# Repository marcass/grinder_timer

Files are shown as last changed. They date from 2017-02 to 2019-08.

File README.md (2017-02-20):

# grinder_timer
timer switch for coffee grinder
* Adjustable time for grind or grind on demand
* LCD display
* small circuit board for mounting inside grinder chasis

## Timer adjustment
* Option for rotary encoder
* Option for potentiometer

### Rotary encoder

* Useful for user defined adjustment steps (eg 50ms or 100ms)
* Setup a little trickier
* https://forum.arduino.cc/index.php?topic=242356.0 FOR ROATRY ENCODER
* https://github.com/0xPIT/encoder/tree/arduino
* https://www.circuitsathome.com/mcu/reading-rotary-encoder-on-arduino/

### Potentiometer

* Easy setup
* Timer value will change with heat of potentiometer
* Increments depend on temp and potentiometer used
* Using 10k pot

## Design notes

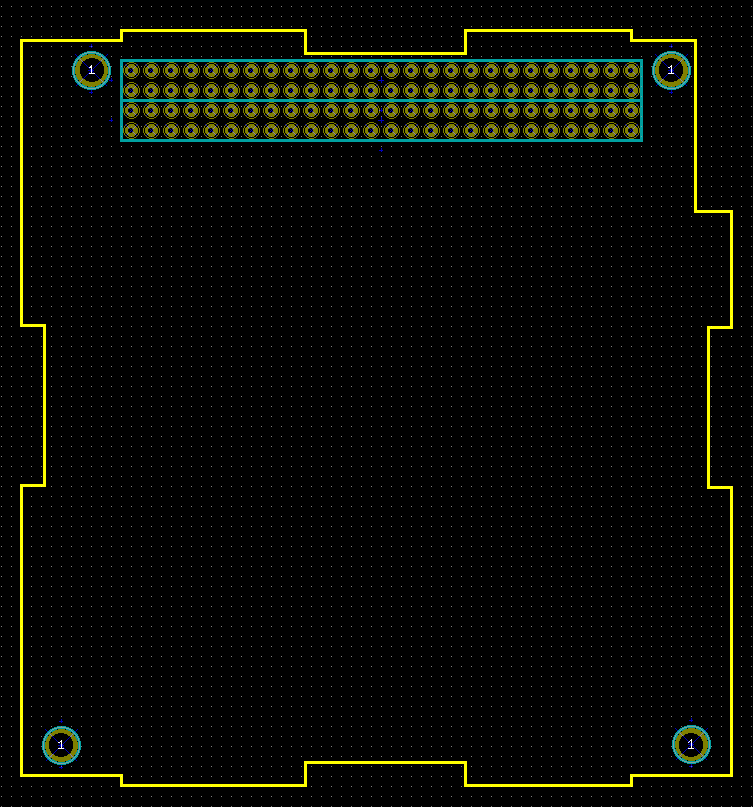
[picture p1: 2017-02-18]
kicad/kicad_lib/KiCad-Libraries-master/Templates/CubeSatKit_StackBoard/meta/Board.png

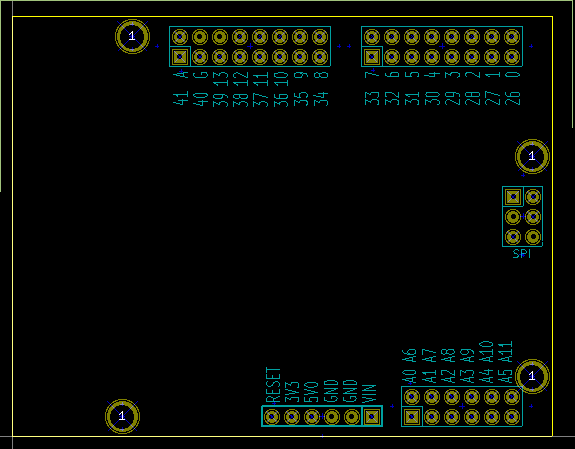
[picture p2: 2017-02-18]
kicad/kicad_lib/KiCad-Libraries-master/Templates/Chipkit_Shield_uC/meta/board.png

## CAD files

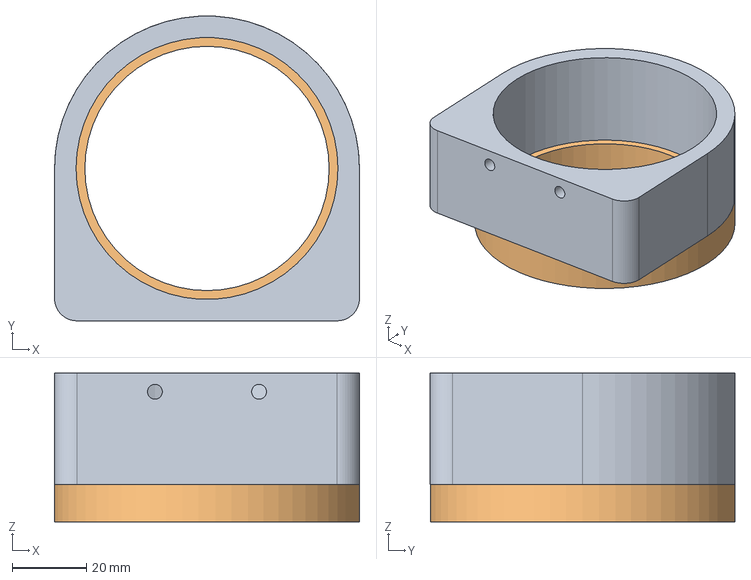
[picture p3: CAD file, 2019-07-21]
cad/grindercad.FCStd
82.1 x 82.0 x 40.0 mm

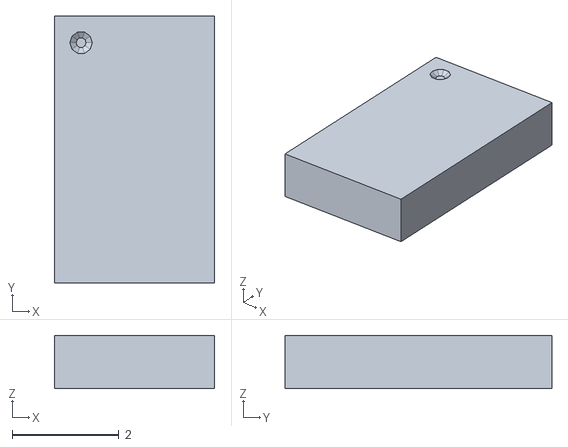
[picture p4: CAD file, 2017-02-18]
kicad/kicad_lib/KiCad-Libraries-master/3D/SourceFiles/ADXL345/ADXL345-Wings.stl
3.00 x 5.00 x 1.00

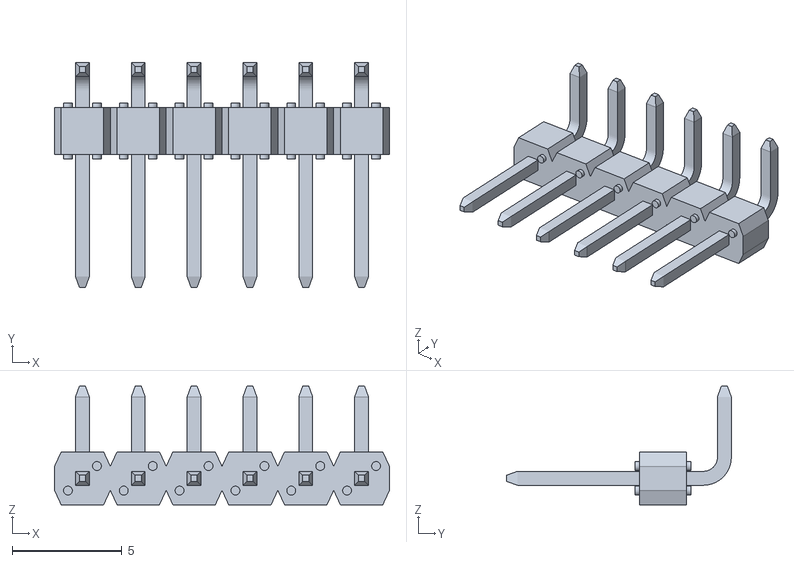
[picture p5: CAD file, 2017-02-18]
kicad/kicad_lib/KiCad-Libraries-master/3D/SourceFiles/Connectors/CONN_1x6/CONN_1x6_Male.stl
15.2 x 10.2 x 5.40

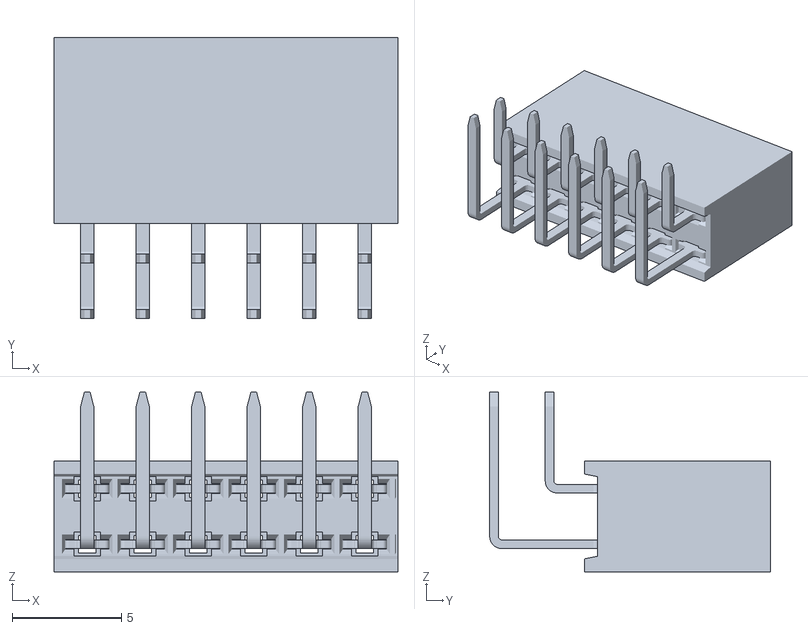
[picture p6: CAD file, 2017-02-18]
kicad/kicad_lib/KiCad-Libraries-master/3D/SourceFiles/Connectors/CONN_2x6/CONN_2x6_Female.stl
15.7 x 12.8 x 8.23

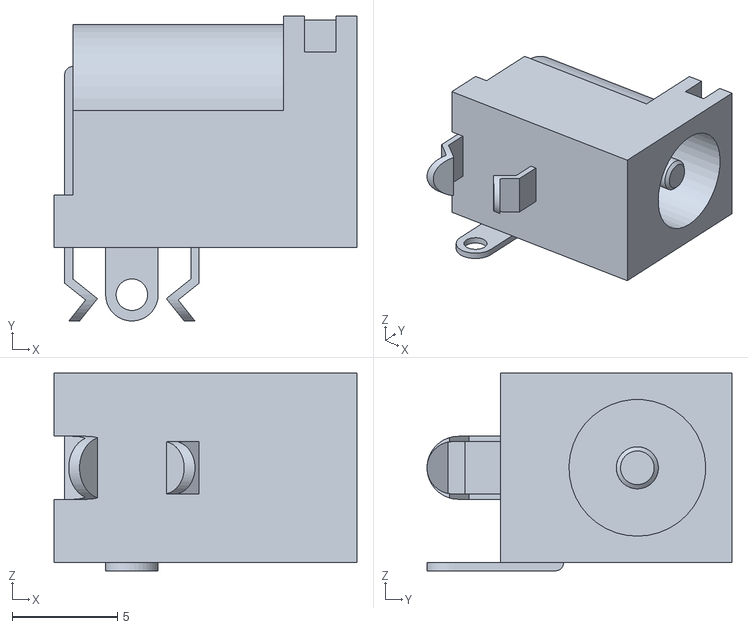
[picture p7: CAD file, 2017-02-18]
kicad/kicad_lib/KiCad-Libraries-master/3D/SourceFiles/Connectors/DC_2.1mm_CUI-PJ-202A/DC_2.1mm_CUI-PJ-202A.stl
14.4 x 14.5 x 9.40

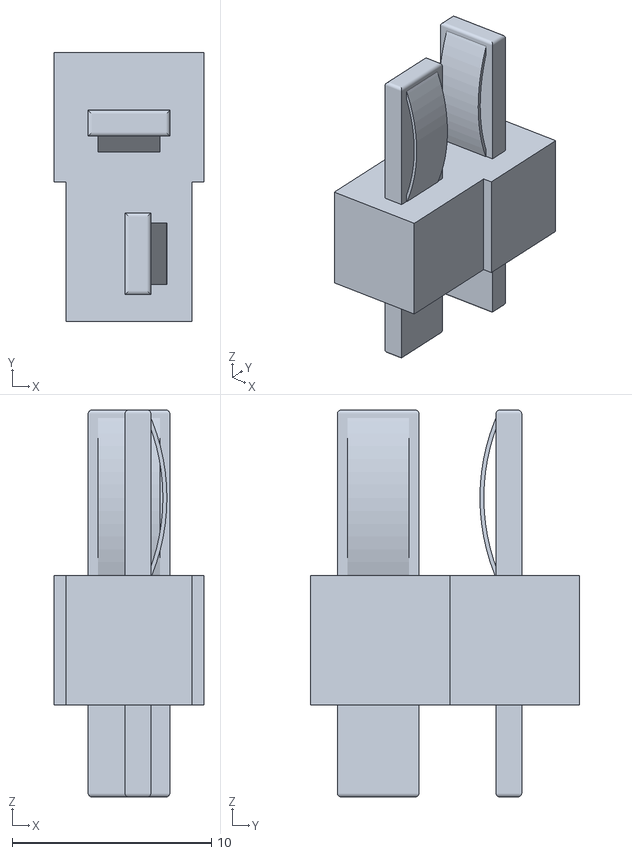
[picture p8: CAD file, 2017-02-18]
kicad/kicad_lib/KiCad-Libraries-master/3D/SourceFiles/Connectors/Deans/Deans-Wings.stl
7.50 x 13.5 x 19.4

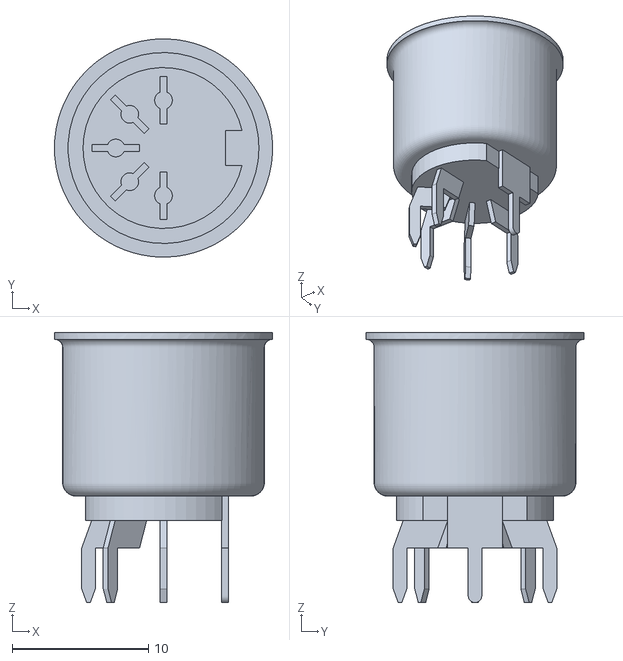
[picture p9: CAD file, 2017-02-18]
kicad/kicad_lib/KiCad-Libraries-master/3D/SourceFiles/Connectors/DIN_CUI_SD-50BV/SD-50BV.stl
16.0 x 16.0 x 19.8

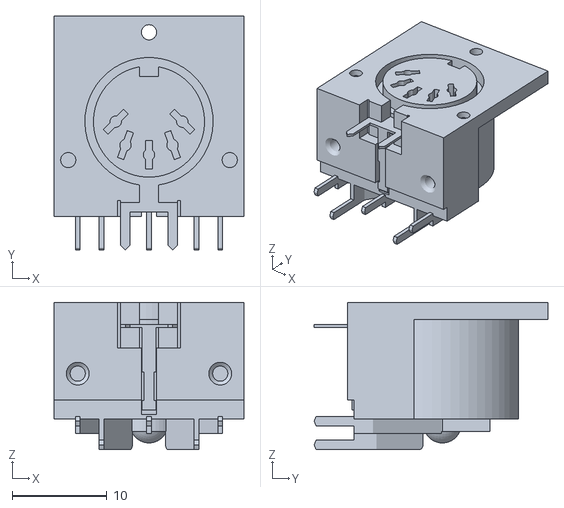
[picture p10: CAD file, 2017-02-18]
kicad/kicad_lib/KiCad-Libraries-master/3D/SourceFiles/Connectors/DIN_CUI_SDS-50J/SDS-50J.stl
20.0 x 24.6 x 15.5

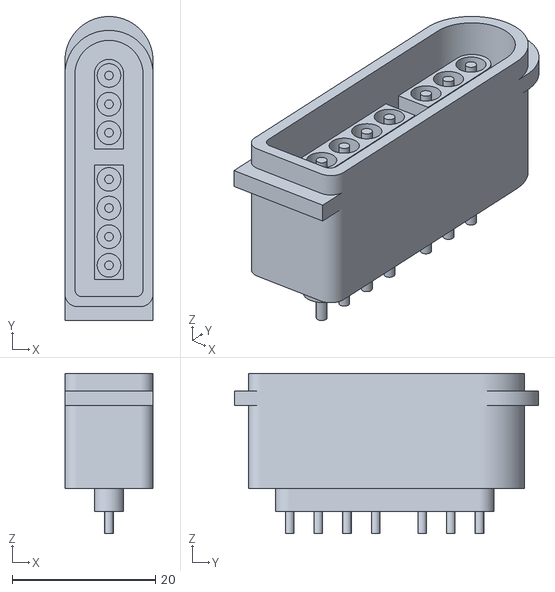
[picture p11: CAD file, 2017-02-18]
kicad/kicad_lib/KiCad-Libraries-master/3D/SourceFiles/Connectors/Gaming_SNES/Gaming_SNES-wings.stl
12.3 x 42.4 x 22.3

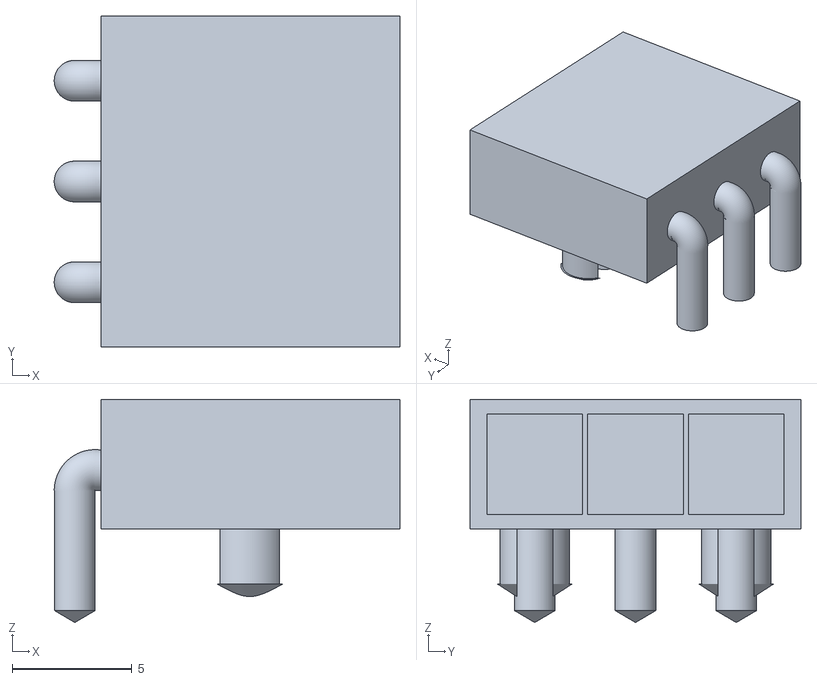
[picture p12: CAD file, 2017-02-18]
kicad/kicad_lib/KiCad-Libraries-master/3D/SourceFiles/Connectors/MOLEX_MINI-FIT-JR_3_PTH_RT_PEG/MOLEX_MINI-FIT-JR_3_PTH_RT_PEG-scad.stl
14.4 x 13.8 x 9.30

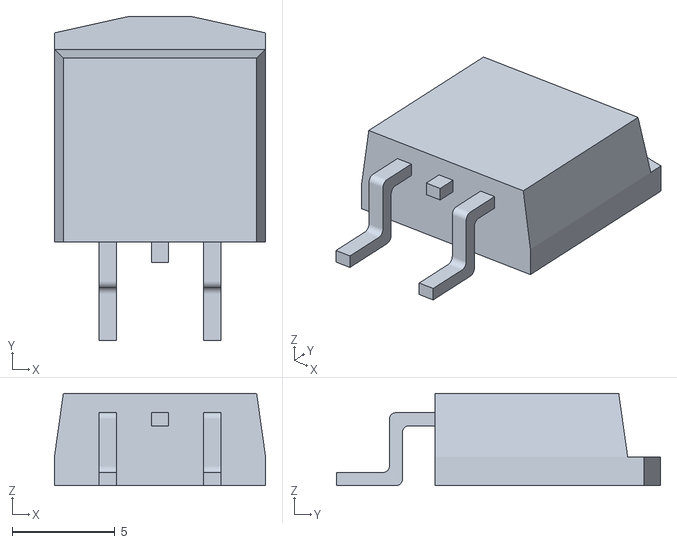
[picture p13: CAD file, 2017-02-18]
kicad/kicad_lib/KiCad-Libraries-master/3D/SourceFiles/D2PACK/D2PACK-SCAD.stl
10.3 x 15.8 x 4.50

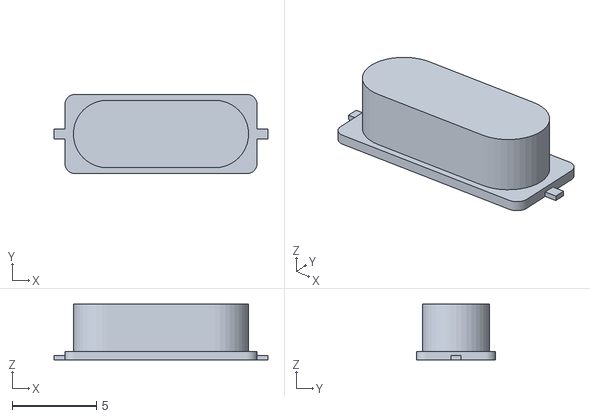
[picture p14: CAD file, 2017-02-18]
kicad/kicad_lib/KiCad-Libraries-master/3D/SourceFiles/HC-49-SMT/HC-49-SMT-wings.stl
12.7 x 4.70 x 3.30

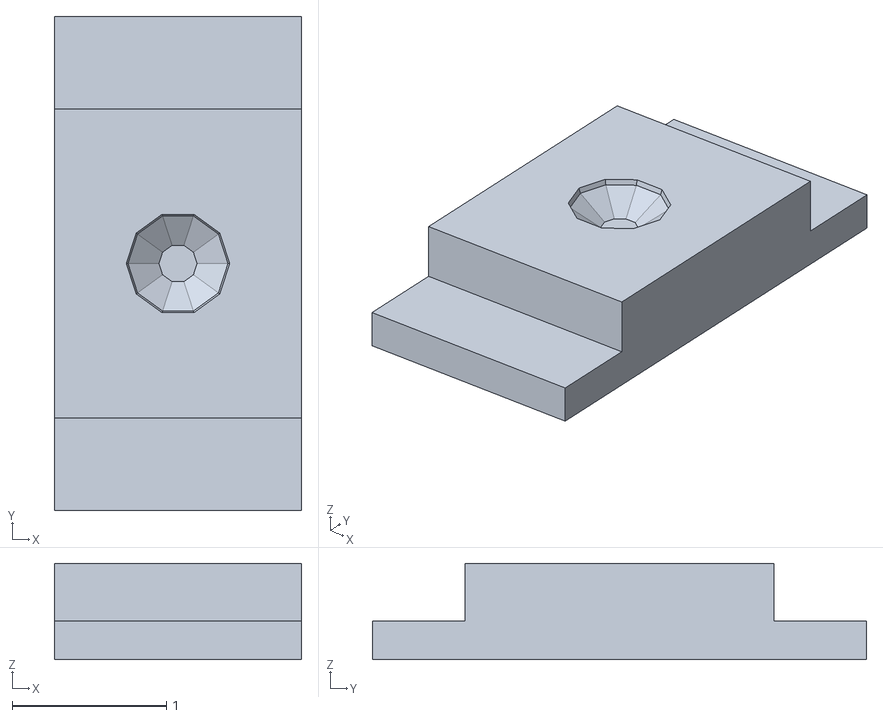
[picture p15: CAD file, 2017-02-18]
kicad/kicad_lib/KiCad-Libraries-master/3D/SourceFiles/LEDs/LED-1206-SCAD.stl
1.60 x 3.20 x 0.625

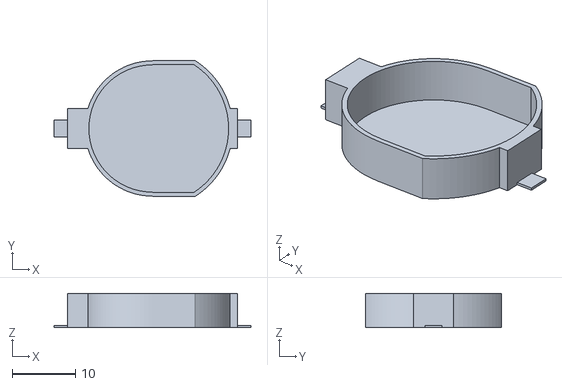
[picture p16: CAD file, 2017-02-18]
kicad/kicad_lib/KiCad-Libraries-master/3D/SourceFiles/MPD_CR2032/MPD_CR2032-Wings.stl
31.1 x 21.4 x 5.38

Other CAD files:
kicad/kicad_lib/KiCad-Libraries-master/3D/SourceFiles/MPU9150/MPU9150-SCAD.stl
kicad/kicad_lib/KiCad-Libraries-master/3D/SourceFiles/SD_Objects/SD-Amp-microSlot-Wings.stl
kicad/kicad_lib/KiCad-Libraries-master/3D/SourceFiles/Sensors/SHARP_GP1A57HRJ00F-wings.stl
kicad/kicad_lib/KiCad-Libraries-master/3D/SourceFiles/SMD_Passives/SMD-1206-scad.stl
kicad/kicad_lib/KiCad-Libraries-master/3D/SourceFiles/Sensors/SHARP_GP1A57HRJ00F.scad
kicad/kicad_lib/KiCad-Libraries-master/3D/SourceFiles/ADXL345/ADXL345.scad
kicad/kicad_lib/KiCad-Libraries-master/3D/SourceFiles/D2PACK/D2PACK.scad
kicad/kicad_lib/KiCad-Libraries-master/3D/SourceFiles/HC-49-SMT/HC-49-SMT.scad
kicad/kicad_lib/KiCad-Libraries-master/3D/SourceFiles/ADXL345/ADXL345-SCAD.stl
kicad/kicad_lib/KiCad-Libraries-master/3D/SourceFiles/Connectors/CONN_1x6/CONN_1x6_Female.stl
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

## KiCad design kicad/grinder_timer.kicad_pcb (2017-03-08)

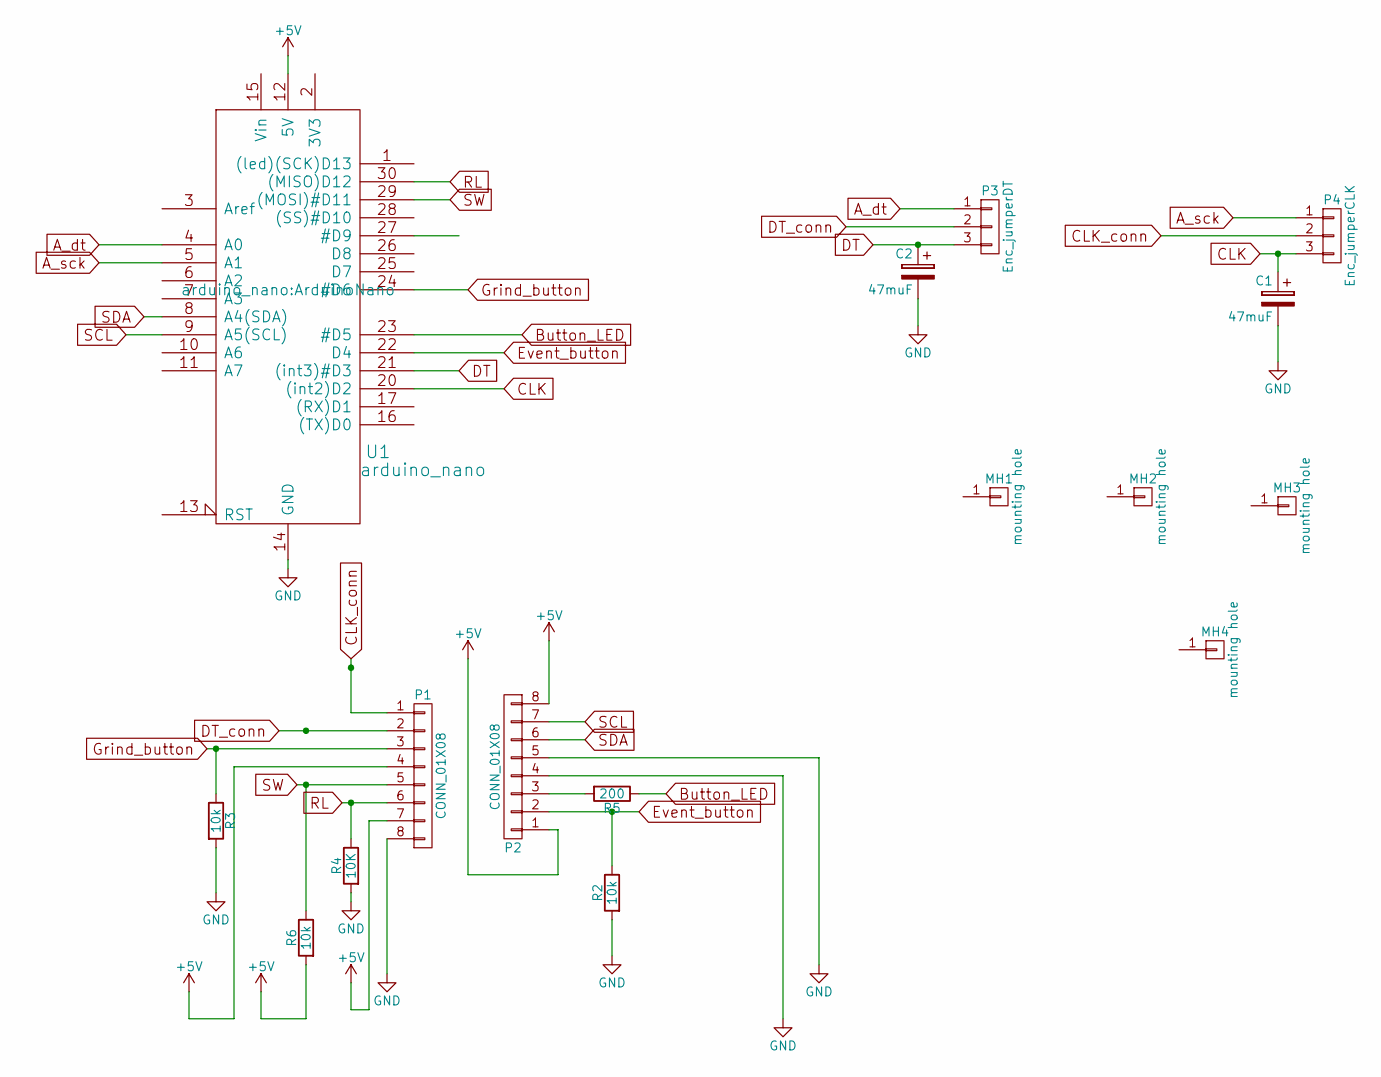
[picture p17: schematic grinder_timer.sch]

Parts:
C1, C2: 47muF; CP_Radial_D10.0mm_P3.50mm
MH1, MH2, MH3, MH4: mounting hole; MountingHole_3.2mm_M3_DIN965_Pad
P1, P2: CONN_01X08; PhoenixContact_MCV-G_08x3.50mm_Vertical
P3: Enc_jumperDT; Pin_Header_Straight_1x03
P4: Enc_jumperCLK; Pin_Header_Straight_1x03
R2, R3, R6: 10k; R_Axial_DIN0207_L6.3mm_D2.5mm_P10.16mm_Horizontal
R4: 10K; R_Axial_DIN0207_L6.3mm_D2.5mm_P10.16mm_Horizontal
R5: 200; R_Axial_DIN0207_L6.3mm_D2.5mm_P10.16mm_Horizontal
U1: arduino_nano; ArduinoNano

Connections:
+5V: P1.4, P1.7, P2.1, P2.8, R6.2, U1.12 (5V)
A_dt: P3.1, U1.4 (A0)
A_sck: P4.1, U1.5 (A1)
Button_LED: R5.1, U1.23 (#D5)
CLK: C1.1, P4.3, U1.20 ((int2)D2)
CLK_conn: P1.1, P4.2
DT: C2.1, P3.3, U1.21 ((int3)#D3)
DT_conn: P1.2, P3.2
Event_button: P2.2, R2.1, U1.22 (D4)
GND: C1.2, C2.2, P1.8, P2.4, P2.5, R2.2, R3.2, R4.2, U1.14 (GND), U1.19 (GND)
Grind_button: P1.3, R3.1, U1.24 (#D6)
unnamed: P2.3, R5.2
RL: P1.6, R4.1, U1.30 ((MISO)D12)
SCL: P2.7, U1.9 (A5(SCL))
SDA: P2.6, U1.8 (A4(SDA))
SW: P1.5, R6.1, U1.29 ((MOSI)#D11)

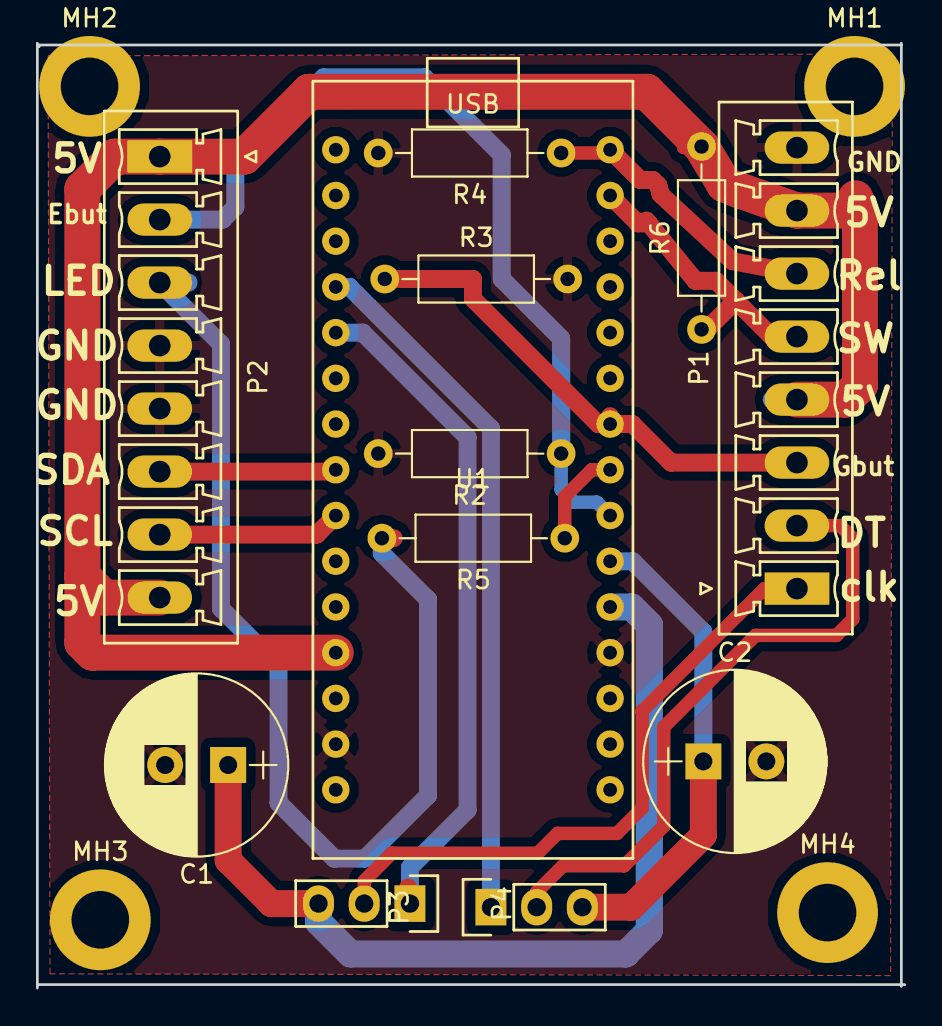
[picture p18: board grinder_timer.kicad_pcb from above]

Board: 2 copper layers, 48.2 x 52.5 mm, 16 parts (0 on the bottom side), 16 nets.

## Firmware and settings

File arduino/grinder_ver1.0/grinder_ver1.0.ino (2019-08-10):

//Runs a mazzer superjolly grinder with timer

#define debug

#include <Wire.h>
#include <Adafruit_GFX.h>
#include <Adafruit_SSD1306.h>
#include <Fonts/FreeSans12pt7b.h>

//preset storage (from reboot for rotary encoder value)
#include <EEPROM.h>
#include "./EEPROMAnything.h"
//#include "/home/mw/git/grinder_timer/rot_encoder_live/EEPROMAnything.h"

struct config_t
{
   int preset;
} configuration;

//******************** setup encoder*************
#define ENC_PORT PINC
const int CLK = A0;
const int DT = A1; 


//*********************** Setup dislplay ************
#define SCREEN_WIDTH 128 // OLED display width, in pixels
#define SCREEN_HEIGHT 64 // OLED display height, in pixels

// Declaration for an SSD1306 display connected to I2C (SDA, SCL pins) adn no reset pin
Adafruit_SSD1306 display(SCREEN_WIDTH, SCREEN_HEIGHT, &Wire, -1);


//************************ presets ***************
const int MIN_GRIND_TIME = 5000;
const int MAX_GRIND_TIME = 15000;
const int STATE_IDLE = 0;
const int STATE_GRINDING = 1;
const int STATE_DONE = 2;
const int MODE_TIMER = 0;
const int MODE_DEMAND = 1;
const int COOL_DOWN = 3000; //number of seconds to cool down after grinding
const long EEPROM_ADJ_THRESH = 600000; //10min
const int DEBOUNCE_DELAY = 50;
//pins
const int GRIND_BUTTON = 6;
const int EVENT_BUTTON = 5; 
const int STATUS_LED_PIN = 9; // pin9 is a PWM pin and allows for analogWrite.
const int RELAY_PIN_L = 12;

//********************* variables ******************
unsigned long grind_time_preset;
unsigned long new_preset;
unsigned long grind_start = 0;
unsigned long grind_time = 0;
unsigned long adjust_time_start = 0;
char buf[16];
int state = STATE_IDLE;
int mode = MODE_TIMER;
bool newPreset = false;
bool timer_starts;
unsigned long mode_debounce_time = 0;
unsigned long grind_debounce_time = 0;
int status_led_brightness = 0;
int fade_rate = 10;
bool change_disp = true;


void setup() {
  //Initialise display
  if(!display.begin(SSD1306_SWITCHCAPVCC, 0x3C)) { // Address 0x3D for 128x64
    Serial.println(F("SSD1306 allocation failed"));
    for(;;);
  }
  delay(2000);
  display.clearDisplay();
  // initialize the button pin as an input
  pinMode(GRIND_BUTTON, INPUT);
  digitalWrite(GRIND_BUTTON, LOW);
  // initialize the button LED as an output
  pinMode(STATUS_LED_PIN, OUTPUT);
  // initialize the RELAY as an output
  pinMode(RELAY_PIN_L, OUTPUT);
  digitalWrite(RELAY_PIN_L, LOW);  
  //initialize event button
  pinMode(EVENT_BUTTON, INPUT);
  digitalWrite(EVENT_BUTTON, LOW); 
  /* Setup encoder pins as inputs */
  pinMode(CLK, INPUT);
  digitalWrite(CLK, HIGH);
  pinMode(DT, INPUT);
  digitalWrite(DT, HIGH);
  Serial.begin (115200);
  Serial.println("Start");
  //read preset storage
  EEPROM_readAnything(0, configuration);
  if (configuration.preset == -1) {
    grind_time_preset = 6000;
  }else {
    grind_time_preset = configuration.preset;
  }
  EEPROM_writeAnything(0, configuration);
//  Serial.print("Grind time preset = ");
//  Serial.println(grind_time_preset);
  // initialize display
  display.clearDisplay();
  display.setFont(&FreeSans12pt7b);
  display.setTextSize(1);
  display.setTextColor(WHITE);
  display.setCursor(0, 20);
  // Display static text
  display.println("Lets Grind");
  display.display(); 
  delay(2000);
  update_display();
}


void update_display(){
  switch (state) { 
    case STATE_GRINDING:
      if (mode==MODE_TIMER) {
        float bar_frac;
        bar_frac = (float)grind_time/(float)grind_time_preset * 100;
        #ifdef debug
          Serial.print("Grind time is: ");
          Serial.print(grind_time);
          Serial.print(", Preset is: ");
          Serial.print(grind_time_preset);
          Serial.print(", bar_frac is: ");
          Serial.println(bar_frac);
        #endif
        display.clearDisplay();
        display.setFont();
        display.setTextSize(1);
        display.setTextColor(WHITE);
        display.setCursor(0, 0);
        display.println("Crushing beans...");
        drawPercentbar( 0, 40, 128, 20, (int)bar_frac);
        display.display();
      }
      if (mode == MODE_DEMAND) {
        display.clearDisplay();
        display.setFont(&FreeSans12pt7b);
        display.setTextSize(1);
        display.setTextColor(WHITE);
        display.setCursor(0, 20);
        display.println("GRAAHHH...");
        display.display();
      }
      break;
    case STATE_IDLE:
      if(change_disp) {
        display.clearDisplay();
//        for bigger sans serif text
//        display.setFont(&FreeSans12pt7b);
//        display.setTextSize(1);
//        display.setTextColor(WHITE);
//        display.setCursor(0, 20);
//        for mono small text
        display.setFont();
        display.setTextSize(1);
        display.setTextColor(WHITE);
        display.setCursor(0, 0);
        // Display static text
        if (mode == MODE_DEMAND){
          display.println("Mode: Demand");
          display.setFont(&FreeSans12pt7b);
          display.setCursor(0, 40);
          display.println("I await");
        }else{
          display.println("Mode: Timer");
          display.setFont(&FreeSans12pt7b);
          display.setCursor(0, 40);
          display.print(grind_time_preset);
          display.println(" ms");
//          display.setCursor(0, 60);
//          display.println("grind");
        }        
        display.display(); 
        change_disp = false;
      }
      break;
    case STATE_DONE:
      display.clearDisplay();
      display.setFont(&FreeSans12pt7b);
      display.setTextSize(1);
      display.setTextColor(WHITE);
      display.setCursor(0, 20);
      // Display static text
      display.println("Done");
      display.setCursor(0, 40);
      display.setFont();
      display.println("Calming down");
      display.setCursor(0,50);
      display.println("Be patient");
      display.display();
      change_disp = true;
      break;
  }
}

void mode_change() {
  if (mode == MODE_TIMER) {
    mode = MODE_DEMAND;
    delay(500);
  }
  else if (mode == MODE_DEMAND) {
    mode = MODE_TIMER;
    delay(500);
  }
  change_disp = true;
}


void proc_idle() {
 static uint8_t counter = 0;   //this variable will be changed by encoder input
 int8_t tmpdata;
 int x;
 /**/
  tmpdata = read_encoder();
  if( tmpdata ) {
//    Serial.print("Counter value: ");
//    Serial.print(counter, DEC);
//    Serial.print("tmpdata: ");
//    Serial.print(tmpdata);   
//    Serial.print("  Grind time = ");
//    Serial.println(grind_time_preset);
    counter += tmpdata;
    x = counter % 4;
    if (x == 0) {
      new_preset = (grind_time_preset + (tmpdata * 50));
      if (new_preset > MAX_GRIND_TIME) {
        grind_time_preset = MAX_GRIND_TIME;
      }else if (new_preset < MIN_GRIND_TIME) {
        grind_time_preset = MIN_GRIND_TIME;
      }else {
        grind_time_preset = new_preset;
      }
      change_disp = true;
      update_display();
      newPreset = true;
    }
//  Serial.print("Counter value: ");
//  Serial.print(counter, DEC);
//  Serial.print("  Grind time = ");
//  Serial.println(grind_time_preset);
  }
  if (digitalRead(EVENT_BUTTON) == HIGH) { 
  //do debounce stuff
  if (mode_debounce_time == 0){
    mode_debounce_time = millis();
    }
    if (millis() - mode_debounce_time > DEBOUNCE_DELAY) {
      //over debounce threshold so change mode
      mode_debounce_time = 0;
      mode_change();
      update_display();
    }
  }
  if (mode == MODE_TIMER) {
    if (digitalRead(GRIND_BUTTON) == HIGH) { 
      //do debounce stuff
      if (grind_debounce_time == 0){
        grind_debounce_time = millis();
      }
      if (millis() - grind_debounce_time > DEBOUNCE_DELAY) {
        //over debounce threshold so change state
        grind_start = 0;
        grind_time = 0;
        timer_starts = true;
        state = STATE_GRINDING;
        update_display();
        grind_debounce_time = 0;
      }
    }
  }
  //if not in timer mode need to grind on button push
  if (mode == MODE_DEMAND) {
    if (digitalRead(GRIND_BUTTON) == HIGH) { 
      //do debounce stuff
      if (grind_debounce_time == 0){
        grind_debounce_time = millis();
      }
      if (millis() - grind_debounce_time > DEBOUNCE_DELAY) {
        //over debounce threshold so change state
        state = STATE_GRINDING;
        update_display();
        grind_debounce_time = 0;
      }
    }
  }
}

void proc_grinding(){
  update_display();
  if (mode == MODE_TIMER) {
    //set flag for timer start
    if (timer_starts) {
      grind_start = millis();
      timer_starts = false;
    }
    grind_time = millis() - grind_start;   //grinding ends if grind time reached or event button is pressed to cancel
    if (grind_time > grind_time_preset){
      #ifdef debug
        Serial.println("dropped out of grinding due to time reset trigger");
      #endif
      state = STATE_DONE;
      update_display();
    }
    //handle a cancellation with push of event button
    if (digitalRead(EVENT_BUTTON) == HIGH) { 
    //do debounce stuff
      if (mode_debounce_time == 0){
        mode_debounce_time = millis();
      }
      if (millis() - mode_debounce_time > DEBOUNCE_DELAY) {
        //over debounce threshold so stop grinding
        mode_debounce_time = 0;
        #ifdef debug
          Serial.println("Killed by event button");
        #endif
        state = STATE_DONE;
        update_display();
      }
    }
  }
  if (mode == MODE_DEMAND) {   //grind on demand so while button is pushed we will grind
    if (digitalRead(GRIND_BUTTON) == LOW){
      state = STATE_DONE;
      update_display();
    }
  }
}

void proc_done(){
  update_display();
  if (digitalRead(GRIND_BUTTON) == LOW) {
     manage_outputs();
     if (mode == MODE_TIMER) {
       delay(COOL_DOWN);
       state = STATE_IDLE;
     }
     if (mode == MODE_DEMAND) {
       state = STATE_IDLE;
     }
     update_display();
  }
}

void manage_outputs(){
  if (state == STATE_GRINDING){
    digitalWrite(RELAY_PIN_L, HIGH);
//    digitalWrite(RELAY_PIN_N, HIGH);
    analogWrite(STATUS_LED_PIN, status_led_brightness);
    status_led_brightness += fade_rate;    
    if (status_led_brightness <= 0 || status_led_brightness >= 255) {
      fade_rate = -fade_rate;
    }
    //delay(1); // delay to see fade
  }else{
    digitalWrite(RELAY_PIN_L, LOW);
//    digitalWrite(RELAY_PIN_N, LOW);
    digitalWrite(STATUS_LED_PIN, HIGH);
  }
}


void loop() {
  manage_outputs();
  switch (state) {
    case STATE_IDLE:
      proc_idle();
      break;
    case STATE_GRINDING:
      proc_grinding();
      break;
    case STATE_DONE:
      proc_done();
      break;
  }
  if (newPreset) { //start timer for EEPROM write
    Serial.println("new preset so waiting");
    if (adjust_time_start == 0 ) {
      adjust_time_start = millis();
    }
    if(millis() - adjust_time_start > EEPROM_ADJ_THRESH) {
      configuration.preset = grind_time_preset;
      EEPROM_writeAnything(0, configuration);
      newPreset = false;
      adjust_time_start = 0;
      Serial.print("wrote data  ");
      Serial.println(configuration.preset);
    }
  }
}

void drawPercentbar(int x,int y, int width,int height, int progress) {
//  display.clearDisplay();
  display.setFont();
  display.setTextSize(1);
  float bar = ((float)(width-4) / 100) * progress; 
  display.drawRect(x, y, width, height, WHITE);
  display.fillRect(x+2, y+2, bar , height-4, WHITE);
  // Display progress text
  if( height >= 15){
    display.setCursor((width/2) -3, y+5 );
    display.setTextSize(1);
    display.setTextColor(WHITE);
  if( progress >=50)
    display.setTextColor(BLACK, WHITE); // 'inverted' text
    display.print(progress);
    display.print("%");
  }
//  display.display();
}
 
/* returns change in encoder state (-1,0,1) */
int8_t read_encoder()
{
  static int8_t enc_states[] = {0,-1,1,0,1,0,0,-1,-1,0,0,1,0,1,-1,0};
  static uint8_t old_AB = 0;
  /**/
  old_AB <<= 2;                   //remember previous state
  old_AB |= ( ENC_PORT & 0x03 );  //add current state
  return ( enc_states[( old_AB & 0x0f )]);
}

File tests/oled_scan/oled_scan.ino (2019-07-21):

/*********
  Rui Santos
  Complete project details at https://randomnerdtutorials.com
*********/

#include <Wire.h>

void setup() {
  Wire.begin();
  Serial.begin(115200);
  Serial.println("\nI2C Scanner");
}

void loop() {
  byte error, address;
  int nDevices;
  Serial.println("Scanning...");
  nDevices = 0;
  for(address = 1; address < 127; address++ ) {
    Wire.beginTransmission(address);
    error = Wire.endTransmission();
    if (error == 0) {
      Serial.print("I2C device found at address 0x");
      if (address<16) {
        Serial.print("0");
      }
      Serial.println(address,HEX);
      nDevices++;
    }
    else if (error==4) {
      Serial.print("Unknow error at address 0x");
      if (address<16) {
        Serial.print("0");
      }
      Serial.println(address,HEX);
    }
  }
  if (nDevices == 0) {
    Serial.println("No I2C devices found\n");
  }
  else {
    Serial.println("done\n");
  }
  delay(5000);
}

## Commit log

2017-01-23 Placed mode button. Need to finish later
2017-01-24 added relay for neutral, updated to active low relays and tidied logic
2017-01-26 button logic continues....
2017-01-26 fixed logic issues on switches
2017-01-26 solved some issues, cannot get state to gho form demand to timer and vice versa as varialbe event_press not being updated
2017-01-26 Working now. To do: relays on startup and LCD updates
2017-01-27 Fixed logic issues. Check relays then build!
2017-01-27 fixed relays starting on startup (was connected to pin 13)
2017-01-29 PWM for LED button
2017-01-31 changed grind timer form interrupt to button press in loop
2017-02-01 Pulled mode change out of interrupt and into button read
2017-02-01 Cleaned up and attempted fix for failed event interrupt
2017-02-02 new fix for poor timer after cancel performance
2017-02-02 new new fix for poor timer after cancel performance
2017-02-02 bool test for grinder timer start
2017-02-02 bool test for grinder timer start adn more variable manip
2017-02-02 fix for swithing modes timer failure initially
2017-02-02 fix for swithing modes timer failure initially. again
2017-02-02 fix for swithing modes timer failure initially. again..
2017-02-03 fix for swithing modes timer failure initially. again...
2017-02-03 interrupts chnaged again
2017-02-03 interrupt flags set
2017-02-03 remove all double refs to interrupts
2017-02-05 removed final interrupt
2017-02-18 Remove neutral switching
2017-02-18 added kicad
    [ADXL345-SCAD.stl, ADXL345-Wings.stl, ADXL345.scad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]
2017-02-20 updated sketch for rotary encoder read in loop
2017-02-26 fiddled with rot encoder reader
2017-03-08 changed pin assignments. NOT PWM PIN IN PCB DAMNIT
2017-03-08 modified sketch to give pwm
    [grinder_timer.kicad_pcb, grinder_timer.sch]
2017-03-11 updated for newly arrived rotary encoder
2017-03-12 got the encoder working and displaying
2019-05-03 added adaptor for hopper attachment
    [hopper_coupling.FCStd]
2019-05-06 fucking around wiht cad
    [hopper_coupling.FCStd]
2019-05-06 got some holes
    [hopper_coupling.FCStd]
2019-05-08 final design, now need to do paths
    [hopper_coupling.FCStd]
2019-05-08 trying to slice
    [hopper_coupling.FCStd]
2019-05-09 fiddling with path
    [hopper_coupling.FCStd]
2019-05-10 getting cutting paths sorted slowly
    [hopper_coupling.FCStd]
2019-05-17 fucknig aroudn with patsh
    [hopper_coupling.FCStd]
2019-05-24 fucking free cad
    [hopper_coupling.FCStd]
2019-05-29 plastic coupling
    [hopper_coupling.FCStd]
2019-05-29 plastic hopper stuff
    [hopper_coupling_plastic.FCStd]
2019-05-30 updated grider adaptor
    [grindercad.FCStd]
2019-05-30 rm surplus files
    [hopper_coupling.FCStd, hopper_coupling_plastic.FCStd]
2019-05-31 weird adaptive profiling cut
    [grindercad.FCStd]
2019-07-21 oled testing
    [grinder_timer.sch]
